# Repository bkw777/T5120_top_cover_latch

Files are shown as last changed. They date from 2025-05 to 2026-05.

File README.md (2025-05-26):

# T5120_top_cover_latch

Printable replacement top cover latch parts for SUN / Oracle SPARC Enterprise T5120 & T5220 servers

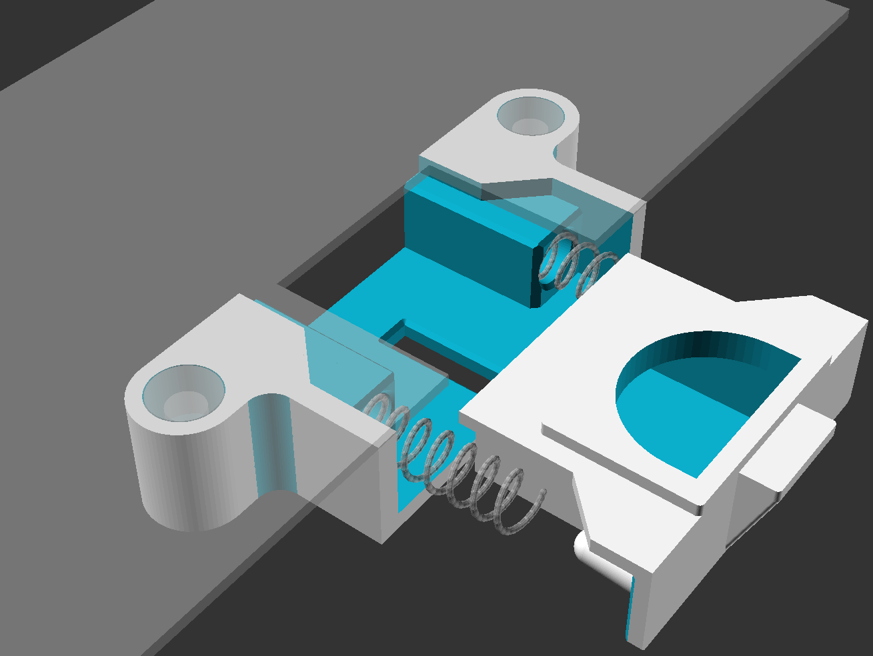
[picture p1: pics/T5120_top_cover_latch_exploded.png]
  
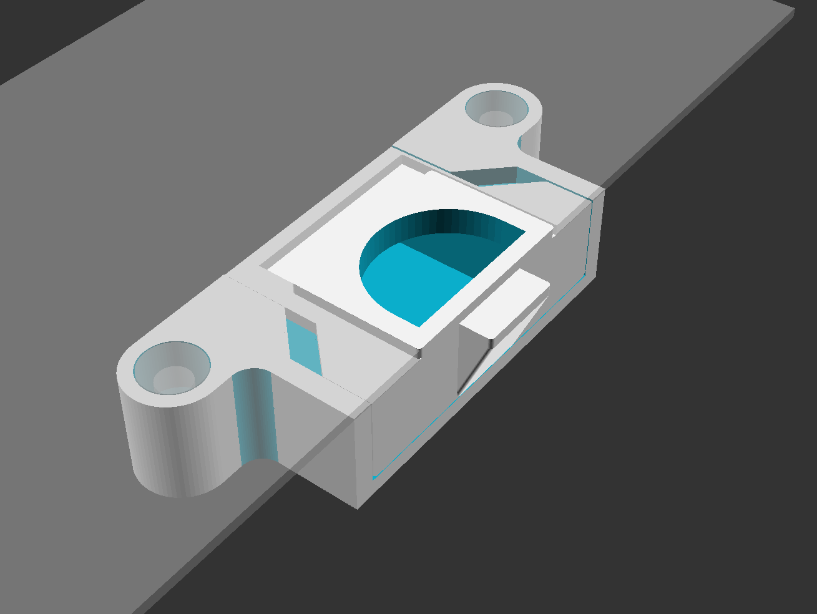
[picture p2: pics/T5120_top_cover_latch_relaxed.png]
  
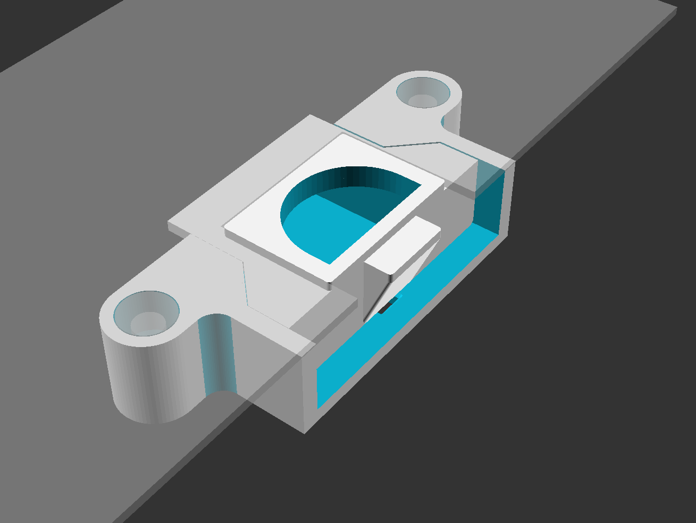
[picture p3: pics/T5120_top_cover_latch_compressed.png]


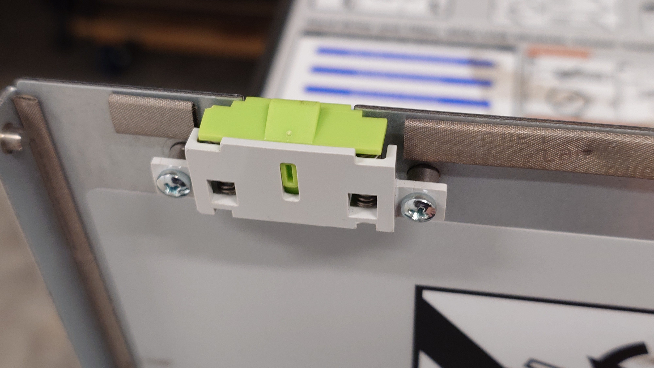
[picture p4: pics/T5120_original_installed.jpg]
  
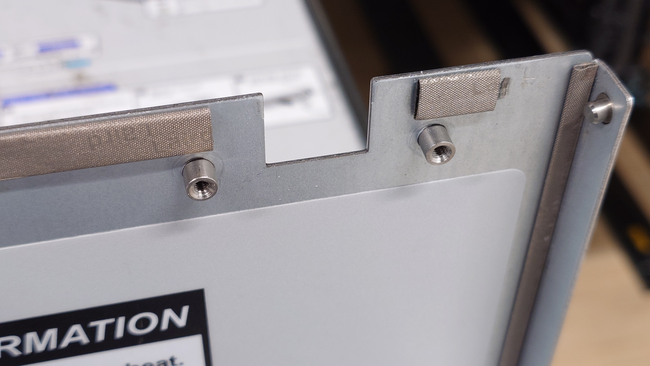
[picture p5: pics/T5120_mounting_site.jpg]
  
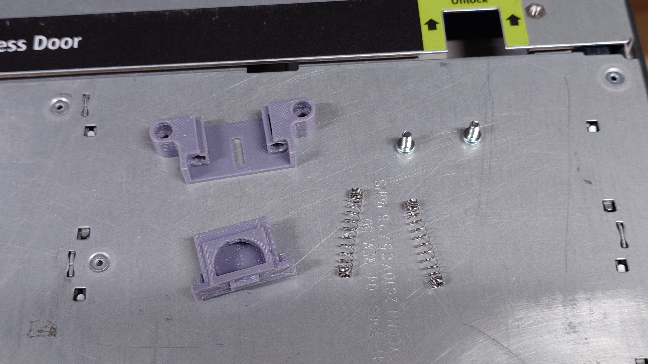
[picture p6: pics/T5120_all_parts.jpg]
  
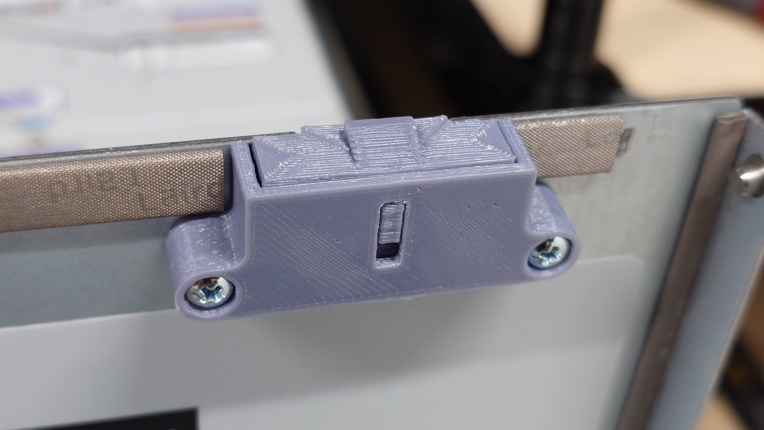
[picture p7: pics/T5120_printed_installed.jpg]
  
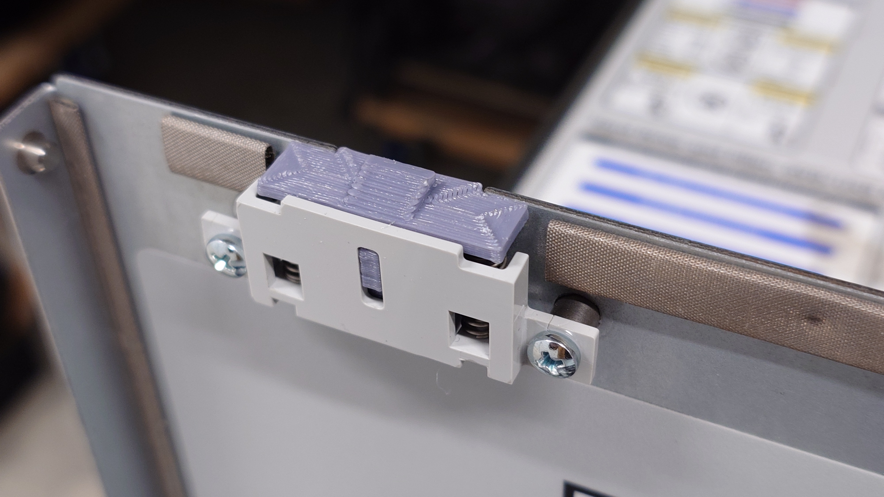
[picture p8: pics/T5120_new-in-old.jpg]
  
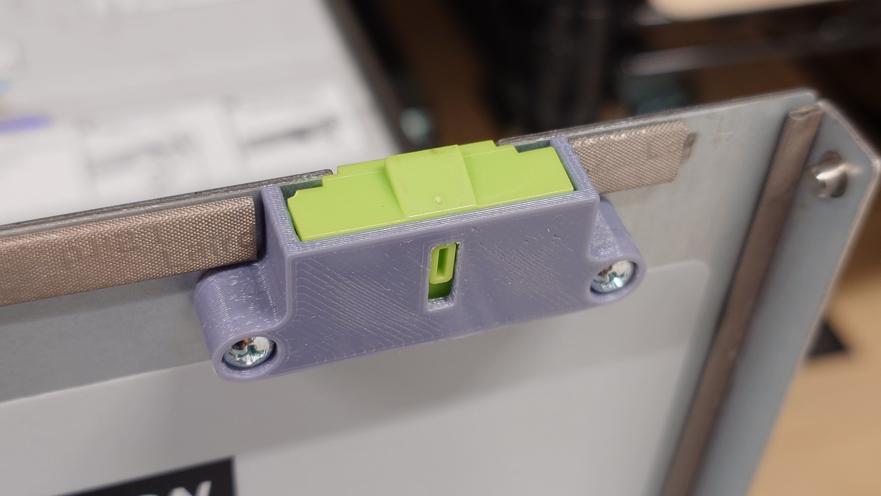
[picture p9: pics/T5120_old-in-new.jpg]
  
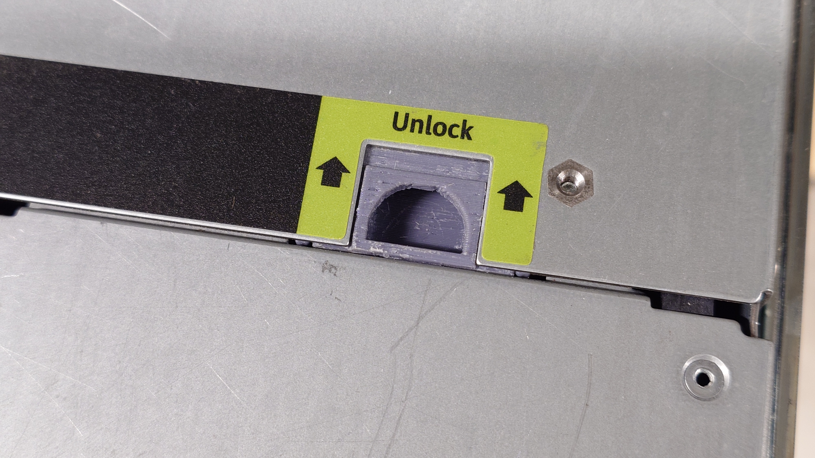
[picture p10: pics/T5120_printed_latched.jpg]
  
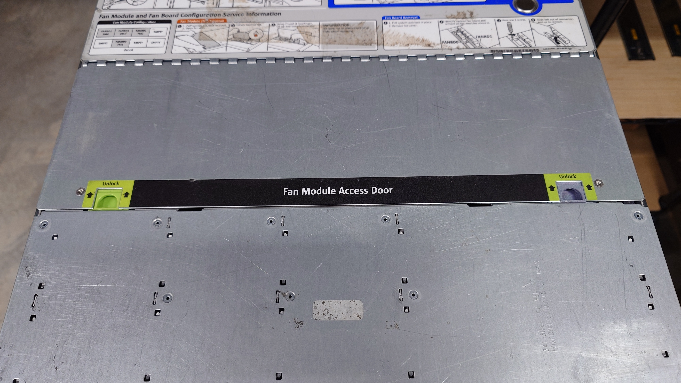
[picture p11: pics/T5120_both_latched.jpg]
  

## compatibility

The new parts are both compatible with the mating original parts.  
So for example if your original frame is broken but you still have the original bolt, you can keep using the original bolt.

## hardware

Common pen springs work in place of the original springs.

The original mounting screws are M3 x 6mm

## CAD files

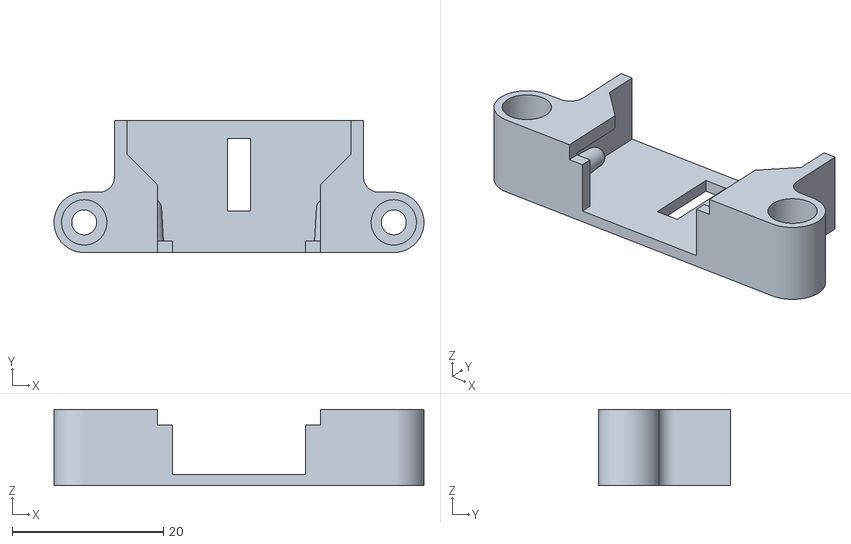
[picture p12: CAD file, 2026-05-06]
stl/T5120_top_cover_latch_FRAME_jawstec.stl
49.0 x 17.5 x 10.1

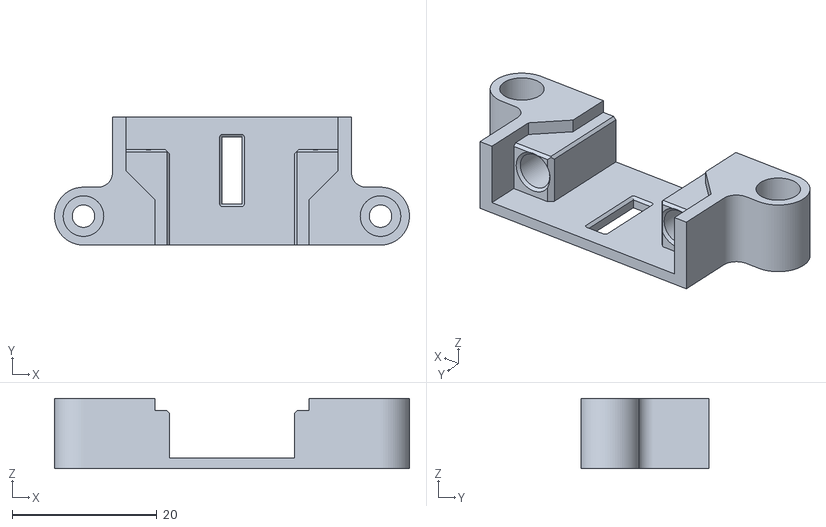
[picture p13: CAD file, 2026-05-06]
stl/T5120_top_cover_latch_FRAME.stl
49.0 x 17.7 x 9.70

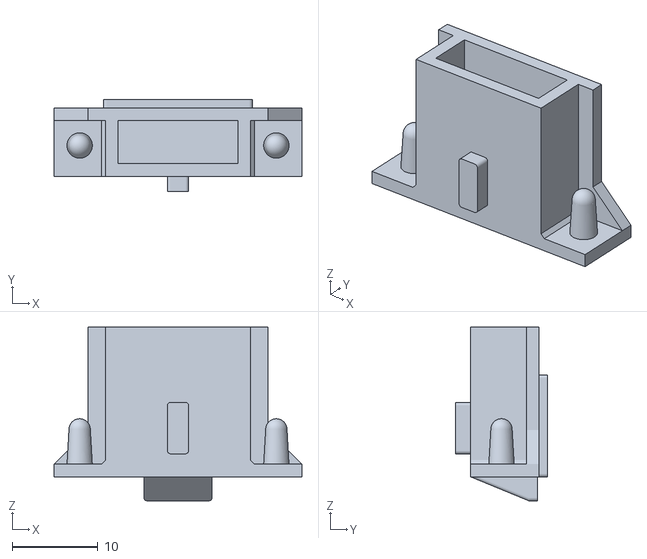
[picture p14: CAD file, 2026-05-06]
stl/T5120_top_cover_latch_BOLT_jawstec.stl
29.0 x 10.8 x 20.3

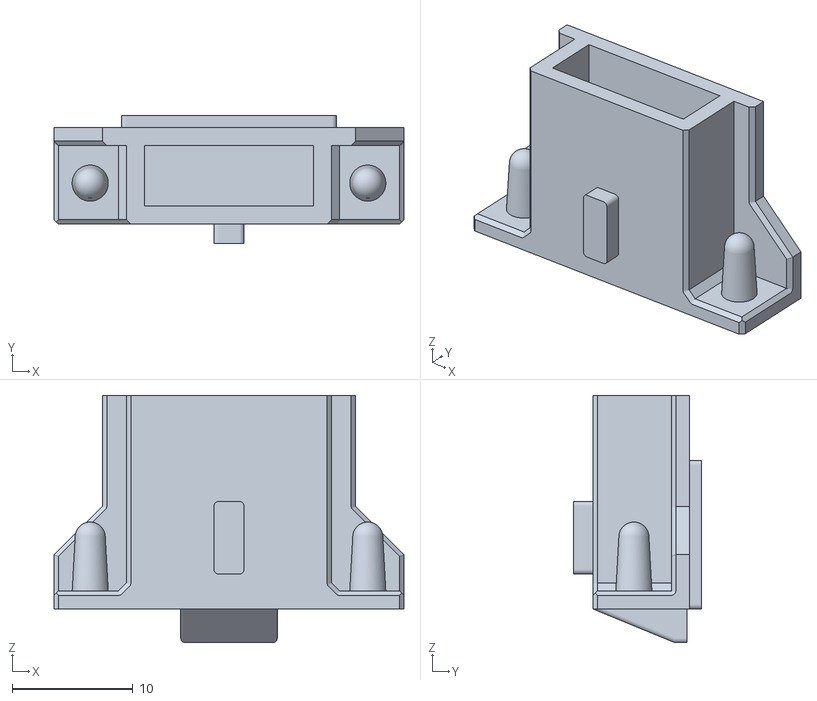
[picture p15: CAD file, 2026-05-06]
stl/T5120_top_cover_latch_BOLT.stl
29.0 x 10.6 x 20.5

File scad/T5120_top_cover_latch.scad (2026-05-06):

// Brian K. White
// top cover door latch for SUN / Oracle Sparc server T5120
// CC BY-SA
//
// frame and bolt both compatible with the original parts
//
// common pen springs work in place of the original springs
// (4.5mm od x 20-25mm length x 0.5mm wire)
//
// screws are M3 x 6mm

// several of these dimensions are fixed
// to keep the parts compatible with the original parts

PRINT = "frame"; // [frame,bolt]

// "flat" for SLS/MJF, "cone" for FDM without supports
SCREW_POCKET = "flat"; // [flat,cone]

fitment_clearance = 0.1; // 0.01
fc = fitment_clearance ;
/* [ Hidden ] */
e = 0.001;

/* [ Global ] */
// If fitement_clearance is greater than this,
// then switch to the alternate JawsTec shit-tolerances shape
// to avoid unprintable thin walls
fc_threshold = 0.15; // 0.01
jawstec = (fc-e>fc_threshold);

screw_flange_thickness = 2.5;

DEBUG_BISECT_Z = "none"; // [none,flange,springs,full]
DEBUG_BISECT_Y = "none"; // [none,screws]
PREVIEW_BOLT_POSITION = "relaxed"; // [compressed,relaxed,exploded]

main_fillet_radius = 4;
fr = main_fillet_radius;

// -1 = auto
chamfer_size = -1; // 0.01

/* [Hidden] */
// not configurable - server case mounting site dimensions
mpcc = 41;   // mount posts center to center
mpod = 5.4;  // mount post od
mph = 4.8;   // mount post height
mpy = 13.8;  // mount post Y (center to front edge)
swid = 18;   // slot width
slen = 15.5; // slot length
cst = 1;     // case sheet thickness

fbw = mpcc-fr-fr; // frame body outside width

// original parts reference dimensions
// configurable if you don't care about
// compatibility with the original parts
sz = 4.7;  // spring z position
spcc = 23; // spring posts center to center
spw = 29;  // spring plate width (the front face)
bfw = 21;  // bolt flange width (the top plate)
lpw = 2.5; // limit pin width
lpd = 6;   // limit pin depth
lpy = 3;   // limit pin Y end to edge

sid = 3+fc;  // screw hole id
shpid = 6+fc*2; // screw head pocket id

/* [Global] */
throw = 3;   // latch throw distance
pawld = throw;   // pawl depth
pawl_top_extra_clearance = 0.2; // 0.01
pawlc = pawl_top_extra_clearance;
pawl_width = 8;
pawlw = pawl_width;

wall_thickness = 1.5;
wt = wall_thickness;

spring_diameter = 4.5; // 0.1
swd = spring_diameter + fc*2; // spring way id
spd = spring_diameter - 1; // spring post od

gusset_covers_gap = !jawstec;
gusset_ext = gusset_covers_gap ? throw : 0;

/* [Hidden] */
bbw = 17;      // bolt body width
bbd = mpy+fr;  // bolt body depth
bbh = 8;       // bolt body height

bt = fc + bbh + fc + wt; // body thickness
btd = slen-throw-fc;     // bolt top depth
wc = (spcc-bbw-swd)/2;   // wing chamfer
wl = (spw-bfw)/2+e; // wing length or big flange gusset size

cs = (chamfer_size<0) ? (wt/4) : chamfer_size ;
//_cs = (chamfer_size<0) ? (wt/4) : chamfer_size ;
//cs = (_cs>0.1) ? sqrt((_cs+fc*2)^2*2) : 0;
//echo ("_cs",_cs);
echo ("cs",cs);

$fn=72;

/////////////////////////////////////////////////////////////////////////////////

module mirror_copy (v = [1, 0, 0]) {
  children();
  mirror(v) children();
}

// square cylinder
// without r1 & r2 = same as rcube without rv & t
// r1 & r2 makes cones / rounded pyramid
module sqyl (w=0,d=0,h=0,r=0,r1=-1,r2=-1) {
 ra = (r1<0) ? r : r1 ;
 rb = (r2<0) ? r : r2 ;
 R = max(ra,rb);
 hull()
   mirror_copy([0,1,0])
     mirror_copy([1,0,0])
       translate([w/2-R,d/2-R,0])
         cylinder(h=h,r1=ra,r2=rb,center=true);
}

module spring (od=10, c=25, l=50, wd=1, s=18, $fn=12) {
    r = (od-wd)/2;    
    ld = (l-wd)/c/360;
    
    translate([0,0,wd/2]) for ( a = [s:s:360*c] ) {
        xa=r*cos(a-s);
        ya=r*sin(a-s);
        za=(a-s)*ld;

        xb=r*cos(a);
        yb=r*sin(a);
        zb=a*ld;

        hull() {
          translate([xa,ya,za]) sphere(d=wd);
          translate([xb,yb,zb]) sphere(d=wd);
        }
    }
}

module springs () {
  od = spring_diameter;        // OD
  wd = 0.5;        // wire diameter
  el = 25;         // exploded length
  rl = bbd-wt-wt-fc;  // relaxed length
  cl = rl-throw;   // compressed length
  c = el/2;   // coils

  l =
    PREVIEW_BOLT_POSITION == "compressed" ? cl :
    PREVIEW_BOLT_POSITION == "relaxed" ? rl :
    el;

  mirror_copy([1,0,0]) translate([spcc/2,fr-wt,sz]) rotate([90,0,0]) spring(od=od,c=c,l=l,wd=wd);
}

module spring_pins () {
  da = spd-0.5;
  db = spd-1;
  gap = fc; // 0, fc, 1
  h = (mpy+fr-wt*2-throw)/2-(db/2)-gap;
  mirror_copy([1,0,0]) translate([spcc/2,0,0]) {
    cylinder(d1=da,d2=db,h=h);
    translate([0,0,h]) sphere(d=db);
  }
}

// the site on the server case where the latch mounts
module site () {
  mirror_copy([1,0,0]) translate([mpcc/2,0,0]) {
    sd = 3;
    sl = 6;
    hd = 6;
    ht = 2.4;
    // screw
    translate([0,0,-sl+mph+screw_flange_thickness]) cylinder(d=3,h=sl+e);
    translate([0,0,mph+screw_flange_thickness]) intersection() {
      cylinder(d=hd,h=ht);
      translate([0,0,-hd+ht]) sphere(r=hd);
    }
    // boss
    cylinder(h=mph,d=mpod);
  }
  translate([0,e-mpy,-cst]) difference() {
    // case sheet
    translate([-50,0,0]) cube([100,50,cst]);
    // slot
    translate([-swid/2,-1,-cst/2]) cube([swid,slen+1,cst*2]);
  }
}

module frame () {

 difference() {

  group () {

    // main body
    // post to post
    hull() mirror_copy([1,0,0]) translate([mpcc/2,0,0]) cylinder(h=bt,r=fr);
    // bolt surround
    translate([-fbw/2,-mpy+fc,0]) cube([fbw,mpy-fc,bt]);
    // fillets
    mirror_copy([1,0,0]) translate([-fbw/2+e,-fr+e,0]) difference() {
      r=2;
      translate([-r,-r,0]) cube([r,r,bt]);
      translate([-r,-r,-1]) cylinder(r=r,h=bt+2);
    }

  }

  group() {
    mirror_copy([1,0,0]) translate([mpcc/2,0,0]) {
      // mount post pocket
      translate([0,0,-e]) cylinder(h=mph,d=fc+mpod+fc);
      // screw head pocket
      if (SCREW_POCKET=="cone") hull() {
        // 45 deg overhang for FDM printing
        ch = (shpid-sid)/2; // chamfer height
        translate([0,0,mph+wt+ch]) cylinder(h=bt,d=shpid);
        translate([0,0,mph+wt]) cylinder(h=ch,d1=sid,d2=shpid);
      } else {
        // flat overhang for MJF/SLS printing
        translate([0,0,mph+screw_flange_thickness]) cylinder(h=bt,d=shpid);
      }
      // screw hole
      cylinder(h=bt*2,d=sid);
    }
    // bolt body way
    translate([0,0,-bt/2+fc+bbh+fc]) cube([fc+bbw+fc,mpy*3,bt],center=true);
    // bolt flange way
    translate([0,0,wt/2+fc-e]) cube([fc+bfw+fc,mpy*3,fc+wt+fc+e*2],center=true);
    // limit pin slot
    lpl = lpd+throw;
    translate([-lpw/2-fc,-mpy+lpy-fc,bbh-1]) cube([fc+lpw+fc,fc+lpl+fc,wt+2]);
    //chamfers
    if (cs && !jawstec) {
      // bolt body-flange chamfer
      mirror_copy([1,0,0]) translate([bbw/2+fc-e,fr-bbd-1,wt+fc+fc+cs]) rotate([0,135,0]) cube([cs*2,bbd+2,cs*2]);
      
      // top of spring way
      translate([spw/2+fc,-mpy+fc+wt+throw-e,wt+fc+fc+cs]) rotate([0,135,90]) cube([cs*2,fc+spw+fc,cs*2]);

      // spring way mouth
      mirror_copy([1,0,0]) translate([spcc/2,-mpy+wt+throw+fc+cs-e,sz]) rotate([90,0,0]) cylinder(d1=swd,d2=swd+cs*2,h=cs);
      // limit pin slot chamfer
      translate([0,lpl/2-mpy+lpy,bbh+cs-e]) sqyl(w=lpw+cs*2+fc*2,d=lpl+cs*2+fc*2,h=cs,r1=cs,r2=0);
    }

    // spring way
      // flange & gusset way
      translate([-spw/2-fc,-mpy-e,-fc-e]) cube([fc+spw+fc,wt+throw+fc+e,bbh+fc+fc+fc+e]);
      // big top flange gusset
      mirror_copy([1,0,0]) {
       translate([bfw/2+fc-e,-mpy+wt+throw+fc-e,-fc-e]) linear_extrude(fc+wt+fc+fc+e) polygon(points = [
        [0, 0],
        [0, wl+gusset_ext],
        [wl, gusset_ext],
        [wl, 0]
       ]);
    }
    if (jawstec) {
      // spring way
      wh = bbh-wt+fc;
      //hull() mirror_copy([1,0,0]) translate([spw/2-wh/2+fc,fr-wt,wh/2+wt+fc]) rotate([90,0,0]) cylinder(d=wh,h=mpy+fr-wt);
      translate([-spw/2-fc,-mpy-e,wt+fc]) cube([fc+spw+fc,mpy+fr-wt,wh]);
    } else {
      mirror_copy([1,0,0]) {
        translate([spcc/2,fr-wt,sz]) rotate([90,0,0]) cylinder(d=swd,h=mpy+fr+1);
        translate([bbw/2+fc/2-e,-mpy+wt+throw+fc-e,fc+fc]) linear_extrude(bbh) polygon(points = [
          [0, 0],
          [0, wc],
          [wc, 0]
         ]);
      }
    }

  }

 }

 // spring pins
 if (jawstec) translate([0,fr-wt+e,sz]) rotate([90,0,0]) spring_pins();

}

module bolt () {
  zadj = fc;
  translate([0,0,zadj]) difference() {
    group() {
      // body
      translate([-bbw/2,-mpy+fc,e]) cube([bbw,bbd-fc,bbh-e]);
      // flange
      translate([-bfw/2,-mpy+fc,e]) cube([bfw,bbd-fc,wt-e]);
      // key
      translate([0,-mpy+lpy+lpd/2,bbh+fc]) sqyl(w=lpw,d=lpd,h=wt*2,r=cs);
      // top
      th = cst+fc;
      td = btd-fc;
      //translate([-swid/2+fc,-mpy+fc,-cst+e]) %cube([swid-fc-fc,btd-fc,cst]);
      translate([0,-mpy+fc+td/2,-th/2+fc+e]) sqyl(w=swid-fc-fc,d=td,h=th,r=cs);
      // spring plate
      translate([-spw/2,-mpy+fc,e]) cube([spw,wt,bbh-e]);
      // spring pins
      translate([0,-mpy+wt-e,sz-zadj]) rotate([-90,0,0]) spring_pins();
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

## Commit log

2025-05-19 add fillets, adjust bolt top depth to match throw
    [T5120_top_cover_latch.scad, T5120_top_cover_latch_BOLT.stl, T5120_top_cover_latch_FRAME_FDM.stl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]
2025-05-20 fitment clearances
    [T5120_top_cover_latch.scad, T5120_top_cover_latch_BOLT.stl, T5120_top_cover_latch_BOLT_(FDM).stl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]
2025-05-20 fix finger pull
    [T5120_top_cover_latch.scad, T5120_top_cover_latch_BOLT.stl, T5120_top_cover_latch_BOLT_(FDM).stl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]
2025-05-24 add gussets to resist PLA creep
    [T5120_top_cover_latch.scad, T5120_top_cover_latch_BOLT_(PLA).stl, T5120_top_cover_latch_FRAME_(PLA).stl]
2025-05-26 small fix to spring plate chamfer
    [T5120_top_cover_latch.scad, T5120_top_cover_latch_BOLT.stl, T5120_top_cover_latch_BOLT_(FDM).stl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]
2025-05-27 organize code, add preview & print orientation options
    [T5120_top_cover_latch.scad, T5120_top_cover_latch_BOLT.stl, T5120_top_cover_latch_FRAME.stl]
2026-01-30 clearance chamfers
    [T5120_top_cover_latch.scad, T5120_top_cover_latch_BOLT.stl, T5120_top_cover_latch_FRAME.stl]
2026-03-22 correct spring pin z, add springs
    [T5120_top_cover_latch.scad, T5120_top_cover_latch_BOLT.stl, T5120_top_cover_latch_FRAME.stl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]
2026-03-24 include springs module, binary stls
    [T5120_top_cover_latch.scad, T5120_top_cover_latch_BOLT.stl, T5120_top_cover_latch_BOLT_jawstec.stl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]
2026-04-02 redraw all chamfers, avoid coincident planes for nicer renders
    [T5120_top_cover_latch.scad, T5120_top_cover_latch_BOLT.stl, T5120_top_cover_latch_BOLT_jawstec.stl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]
2026-05-06 pawl clearance
    [T5120_top_cover_latch.scad, T5120_top_cover_latch_BOLT.stl, T5120_top_cover_latch_BOLT_jawstec.stl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]
